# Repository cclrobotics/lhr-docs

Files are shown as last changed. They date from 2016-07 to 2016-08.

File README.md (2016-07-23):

# lhr-docs
Documentation for the Liquid Handling Robot

# Some resources for docmentation, git, and others.
- [Markdown Cheatsheet](https://github.com/adam-p/markdown-here/wiki/Markdown-Cheatsheet)
- [Atlassian Tutorials](https://www.atlassian.com/git/)

# Collaboration Documentation
- [Q & A with Pedro](https://github.com/cclrobotics/lhr-docs/blob/master/collaborations/Pedro-Terra/07-16-16_Q%26A.md)
- [Igor's Brain Github](https://github.com/arcturusbiocloud/igor-brain)
- [Igor Presentation](https://docs.google.com/presentation/d/1FlfPRDT8VCawL8XQLC20QvG_V_BuOnPto9CB1tIN5D0/edit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)

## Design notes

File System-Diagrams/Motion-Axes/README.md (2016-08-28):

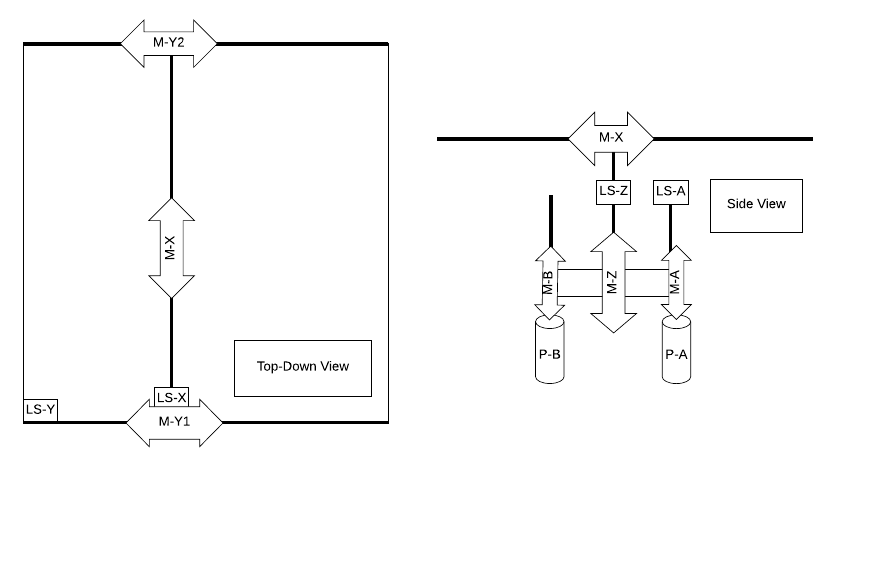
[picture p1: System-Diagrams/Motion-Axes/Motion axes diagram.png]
Motion Axes Diagram
 

|Key | Item | 
|---|---|
| M-X |X-Axis Motor |
| M-Y1 |Y-Axis Motor 1 |
| M-Y2 |Y-Axis Motor 2 |
| M-Z |Z-Axis Motor |
| P-A |Single Channel Pipette |
| P-B |Multi Channel Pipette |
| M-A |A-Axis Motor |
| M-B |B-Axis Motor |
| LS-X |X-Axis Limit Switch |
| LS-Y1 |Y-Axis Limit Switch | 
| LS-Z |Z-Axis Limit Switch |
| LS-A |A-Axis Limit Switch |

##Top-Down View
###X-Axis
There is one X-axis motor (M-X) which is attached to the pipettes and moves along the central beam. It uses the limit switch (LS-X) as it's minimum value, so that end is essentially zero for the X-axis. 
###Y-Axis
There are two Y-axis motors (M-Y1 and M-Y2) which are attached to either end of the central beam. Their phases are inverted so they will travel in synch together, moving the central beam. They use one limit switch (LS-Y1) as the minimum value for the Y-1 motor. This is the zero for the Y-axis. Only Y1 side hits it, and the stop signal should be sent to both Y motors. 

##Side View
###Z-Axis
There is one Z-axis motor (M-Z) which is attached to the set of pipettes and moves up and down perpendicular to the central beam. It uses the limit switch (LS-Z) as it's minimum value. This is the zero for the Z-axis. Moving along the Z-axis in a positive direction translates to moving **down**. 
###A-Axis
There is one A-axis motor (M-A) which is attached to the plunger of the single-channel pipette (P-A). It controls the depression of the plunger allowing us to propgram how much volume is pipetted up/down. It uses the limit switch (LS-A) as it's minimum value. This is the zero for the A-axis.
###B-Axis
There is one B-axis motor (M-B) which is attached to the plunger of the multi-channel pipette (P-B). It controls the depression of the plunger allowing us to propgram how much volume in pipetted up/down. There is currently no limit switch attached for this motor.

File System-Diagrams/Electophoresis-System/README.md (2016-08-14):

#Electophoresis System

http://www.instructables.com/id/Gel-electrophoresis-system-mini/

Diagram of the System here.

What are the components?
- Thing1
- DC-DC Converter
- AC-DC Converter
- More things...

Hardware and tools

From McMaster-Carr:

- 2-56 Hand Tap Taper, Cat # 2522A663
- Tap Wrench Sliding T-Handle, 0-1/4" (1.6-6.3mm) Tap Size, Cat # 2546A22
- 2x 2-56 Nylon Pan Head Slotted Machine Screw, 3/16" Length, Cat # 93135A076
- 4x 2-56 Nylon Pan Head Slotted Machine Screw, 1/8" Length, Cat # 93135A074
- Stainless steel wire, 0.01" diam. Cat # 9882K31
- 2x 6/32 Hex machine nuts Cat # 91841A007
- 2x Flat Washer, No. 6 Screw Size, 5/16"Cat #  92141A008

From TAP Plastics:

- IPS weld-on cement #3 or 4, Cat # 10792
- Hypo-type solvent cement applicator, Cat # 25658

From Digi-Key:

- 2x Banana plug, Cat #655K-ND
- Black banana plug cable, 36", Cat # 4771-36-0-ND
- Red banana plug cable, 36", Cat # 4771-36-2-ND
- 4x Rubber feet , Cat # SJ5012-0-ND

## Thing1

## DC-DC Converter 
It's based on the [Electrophoresis variable power supply](http://public.iorodeo.com/docs/electrophoresis_power_supply/)
by [IO Rodeo](http://iorodeo.com/).
It requires an input voltage from 10V (this hasn't been verified and should be) to 16V.
Manufacturer's recommended input voltage is 15V.
The original unit has a variable output from 25V to 100V. It has been modified to produce an output from 30V to 200V
by substituting the original 15K resistor R3, with a 7.5K resistor. A schematic of the circuit can be found
[here](http://public.iorodeo.com/docs/electrophoresis_power_supply/intro.html).

## AC-DC Converter
This is the thing you plug into the wall.
Triad Wall Mount AC Adapter  WSU150-1600
http://www.mouser.com/ProductDetail/Triad-Magnetics/WSU150-1600/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
It has a 15 V up to 1.6A output.
Note: Any replacement unit cannot have an output greater than 16V or damage to the [DC-DC Converter](#dc-dc-conv)

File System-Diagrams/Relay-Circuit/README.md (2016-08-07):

Several of the instruments are controlled using relay circuits so here is a little information about how they work.
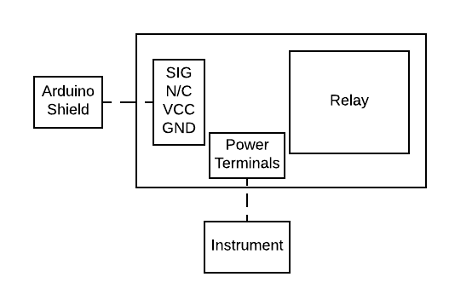
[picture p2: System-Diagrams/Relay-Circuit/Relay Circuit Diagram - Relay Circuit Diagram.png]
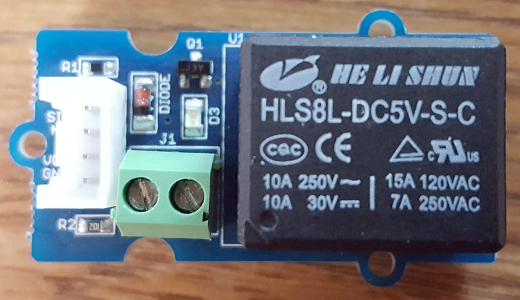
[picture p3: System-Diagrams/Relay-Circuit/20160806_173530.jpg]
 

- Four pin connector on the left links to a shield on the arduino board. The pins are as follows:
  - SIG: Signal from Arduino for the relay to open/close the circuit.
  - N/C: No connection (Doesn't actually do anything, only in place so a common connector can be used)
  - VCC: Provides power from the Arduino for the relay logic.
  - GND: Ground to the Arduino.

- Power Terminals switch power to one of the following instruments by completing their AC connection:
  - Shaker (on/off control)
  - Centrifuge (on/off control)
  - WL Transiluminator (on/off control)
  - UV Transiluminator (on/off control)
  - Incubator (Arduino uses a [hysteresis controller](https://www.google.com) to maintain temperature at 37&deg;C)
  - Igor Light (on/off control, suspected to be the overhead lights)
  - Gel Electrophoresis (on/off control)
  - Shaker Incubator Light (on/off control, there should be an incubator light to warm shaking tubes but I'm not sure where it is)
Some of these are assumed based on the [arduino code](https://github.com/griswaldbrooks/lhr-equipment-controller/blob/master/controller_firmware/controller_firmware.ino).

- Relay
  - Model #: HLS8L-DC5V-S-C
  - The relay receives a signal from the Arduino telling it to close or open the circuit. This will power on or off the instrument connected to the power terminals. Most of these can just be turned on/off (light boxes). In the case of the shaker and centrifuge, they are set to a specific rpm and just turned on/off by the Arduino. The hysteresis controller code is already loaded onto the Arduino. The Incubator also has a temperature sensor attached. When the temperature falls below 37&deg;C the Arduino turns the Incubator power source on (a lamp for now), once the temperature is above 3&deg;7C it is turned off. (We can make this more sophisticated in the future)

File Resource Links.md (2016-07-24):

# Components of the system

## Raspberry Pi
This is the main brain of the system. It is connected to every other aspect of the system and performs the high level planning involved.
There will be various types of code on it.   
- [Website](https://www.raspberrypi.org/)
- [Github](https://github.com/raspberrypi/)

## Smoothieboard 
Used to control stepper motors for XYZ translation and limit switches for setting up boundaries for each axis. 
It is programmed with g-code.   
- [Website](http://smoothieware.org/)
- [Github](https://github.com/Smoothieware/Smoothieboard) 

## Arduino Uno
Used to control the lab equipment (Centrifuge, shaker, etc. Note: PCR controlled via Rasberry pi).
You write sketches the arduino using the Arduino Software (IDE) which uses C/C++ by default.     
- [Website](https://www.arduino.cc/en/Main/ArduinoBoardUno)
- [Github](https://github.com/arduino/Arduino)

## Pronterface
They run a software suite called PrintRun which allows you to communicate with 3D printers, but we will be using it to communicate with the CNC.
This suite is on the rasberry pi and sends g-code to smoothie board.    
- [Website](http://www.pronterface.com/)
- [Github](https://github.com/kliment/Printrun)

# Previous Work

## Pedro Terra  
- [Website](http://www.pedroterralab.com/)

## OpenTrons
The original liquid handling robot, made by Arcturus, that Pedro and Luis modified and expanded into "Igor."  
- [Website](https://opentrons.com/)
- [Github](https://github.com/OpenTrons/otone_docs/blob/master/README.md)
- [Open source bioserver](https://forum.arcturus.io/t/open-source-bioserver/17/9)    
This is a great place to see the progress Pedro and Luis made.
- [BioBot 1.0 Assembly Guide](https://synbiota.com/projects/1p_XD0znG/entries/0DATTrmqW?preview=true)  
Note: The assembly guide is for the original OpenTrons DIY BioBot. Pedro and Luis' "Igor" is larger, includes more components, and most importantly is using the Smoothieboard NOT the TinyG. Therefore it's best we dont' follow this to a T.

### Google Drives
- [OpenTrons](https://drive.google.com/folderview?id=0B5OBQhwEUbwUNXZKVWYxeHo2elE&usp=drive_web)
- [bioserver](https://drive.google.com/folderview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)
- [igor general photos](https://drive.google.com/folderview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)
- [igor bioserver parts](https://drive.google.com/folderview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)

It won't be necessary to exaustivly read through all of their documentation, but these should be good sources to look at if we run into any trouble figuring the system out. I will be compiling files and information from these sources throughout the repo in appropriate locations (ex. photos in a photos folder).

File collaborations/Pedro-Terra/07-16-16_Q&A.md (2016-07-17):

We set up a skype call with Pedro to find out a lot of information that would help us in making the LHR work. It was a very enlightening conversation and I would like to update you all with the information we discussed. I will update any files and information Pedro sends us promply. 
(Thank you Pedro for all of your help thus far!!)

# Summarised Q&A with Pedro:

1. Where is there documentation for all of the aspects of this system (code, system diagrams, circuit diagrams, images, files, etc.)?

  May have sketches in notebooks.
  Models of system available in sketch up files. 

  [Smoothie board website](http://smoothieware.org/) has useful information regarding the CNC wiring, XYZ motor and limit switch code. 
  Smoothie board handles all CNC movement. A axis for plunger to choose volume to pipette is controlled through the smoothie board. All ejection, dispensing, and aspiration is accomplished with one motor. All motor uncertainty is 0.1 mm. 
  [Pronterface](http://www.pronterface.com/) used for doing cnc commands with macros and custom functions. 
  Did not use [Mix.bio](Mix.bio) to write protocols, that was only the [OpenTrons](https://opentrons.com/) people (Will and Chu).
  All code was custom, mostly g-code. Code was written to control the CNC, PCR, incubator lamp, and web functionality. Communicate with Luis Silva for more information about the web connectivity, remote operation and general code questions.

2. How much of the system worked? 
  * **CNC**: 
  
    CNC worked, grabbing and releasing pipette accessories (petri dish,  gel electrophoresis tray) worked, pipetting liquids worked. Main problem how to attach pipette to arm. Pipette attachment to accessories would be affected by the plastic portion of the pipette bending. Pipette not supported well by attachment to robot arm. 
  * **Laser/Camera System**: 
  
    Was used to align pipette during remote operation. Not directly implemented in the control loop for XYZ translation. 
  * **Fridge**: 
  
    Fridge circuit should connect to arduino. 
Fridge is meant to operate between -20˚C (temperature the fridge is intended to be used at) at the bottom and -5˚C near the top. 
Expected to have a jack inside of the fridge to move things closer to the top so they can thaw. 
Should have car jacks. 
  * **Incubator**:
  
    Function was used to turn the incubator on and off to maintain a set temperature. (Temperature sensor that we thought was used for the fridge is actually used to sense this temperature.)
  * **Light Boxes**: 
  
    Not fully implemented. Should use one camera for each lightbox to imagine petri dishes and gels. 
  * **PCR**: 
  
    PCR was connected to Raspberry pi to upload protocols. Check [OpenPCR](http://openpcr.org/) for documentation.
  * **Centrifuge**: 
  
    Not fully implemented. 
  * **Shaker**: 
    
    Not fully implemented. 
  * **Gel Electrophoresis**: 
    
    Not fully implemented. 
  * **Eppendorf tube capper**: 
  
    Separate system used to open and re-cap eppendorf tubes. Not fully implemented or integrated with LHR. 

3. How did the camera system work?

  Used two cameras for alignment with the lasers and gcode for x-y location. 
  Two or three cameras for streaming and remote operation, these were attached to the axes. 
  Two cameras for transiluminator.
  Cameras all plug into raspberry pi. 

4. How did you move eppendorf/PCR tubes ?

  Did not move eppendorf tubes, only PCR tubes. PCR tubes cut into two tube sections. One tube was used to attach the pipette in order to move both tubes around, the second tube was actually used to do labwork in. 
  
5. Were you any exernal resource to find protocols to run the robot with?

  Although OpenTrons used [Mix.bio](Mix.bio) protocols ours were all custom and written in g-code using pronterface. 

6. What are the other rasbperry pis, second PCR, and extra usb hub for?

  These are all redundancies in case any parts of the system need to be replaced. The system should only use one raspberry pi, one PCR, one USB hub, and one arduino. 

7. How do you connect the system to the internet?

  All internet capability should be through the raspberry pi (this suggests the pi should have a rasberry server on it). Contact Luis to for further questions about the internet connectivity.

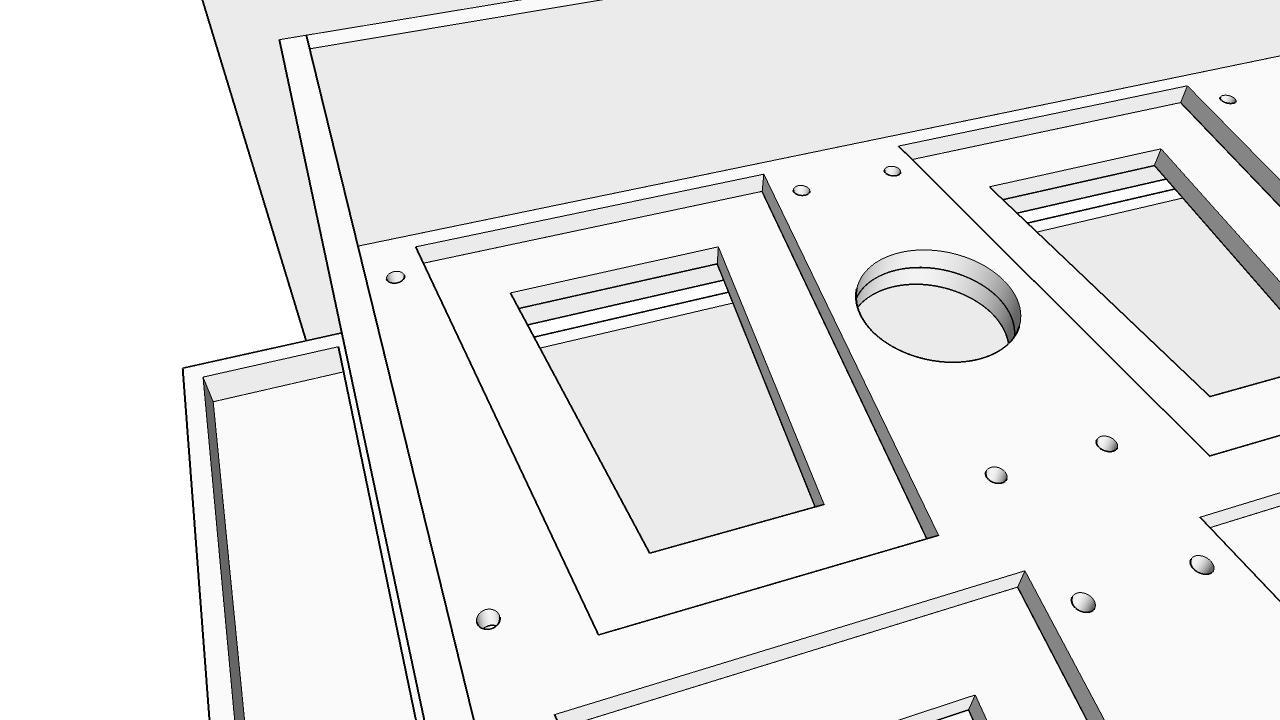
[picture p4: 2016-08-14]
Image/Design-Images-CAD/Arcturus BioCloud incub and robotic System0006.jpg

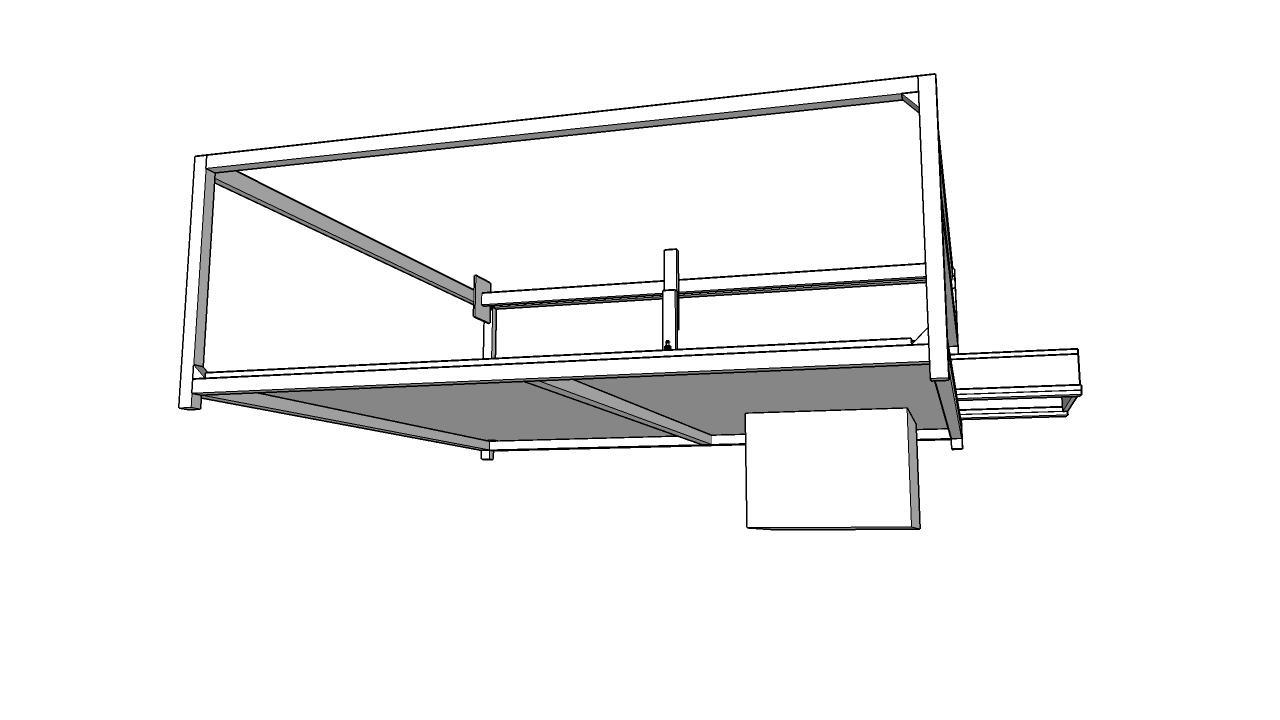
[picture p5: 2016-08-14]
Image/Design-Images-CAD/Arcturus BioCloud incub and robotic System0013.jpg

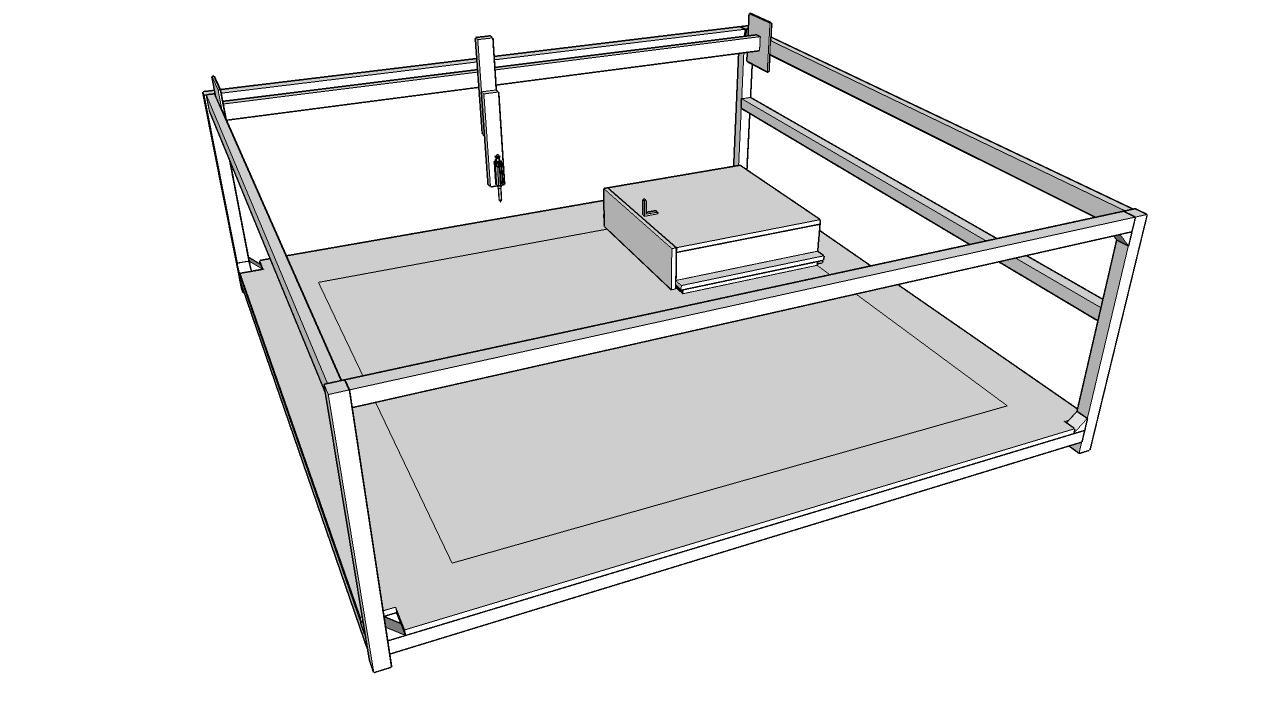
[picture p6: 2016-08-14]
Image/Design-Images-CAD/Arcturus BioCloud incub and robotic System0001.jpg

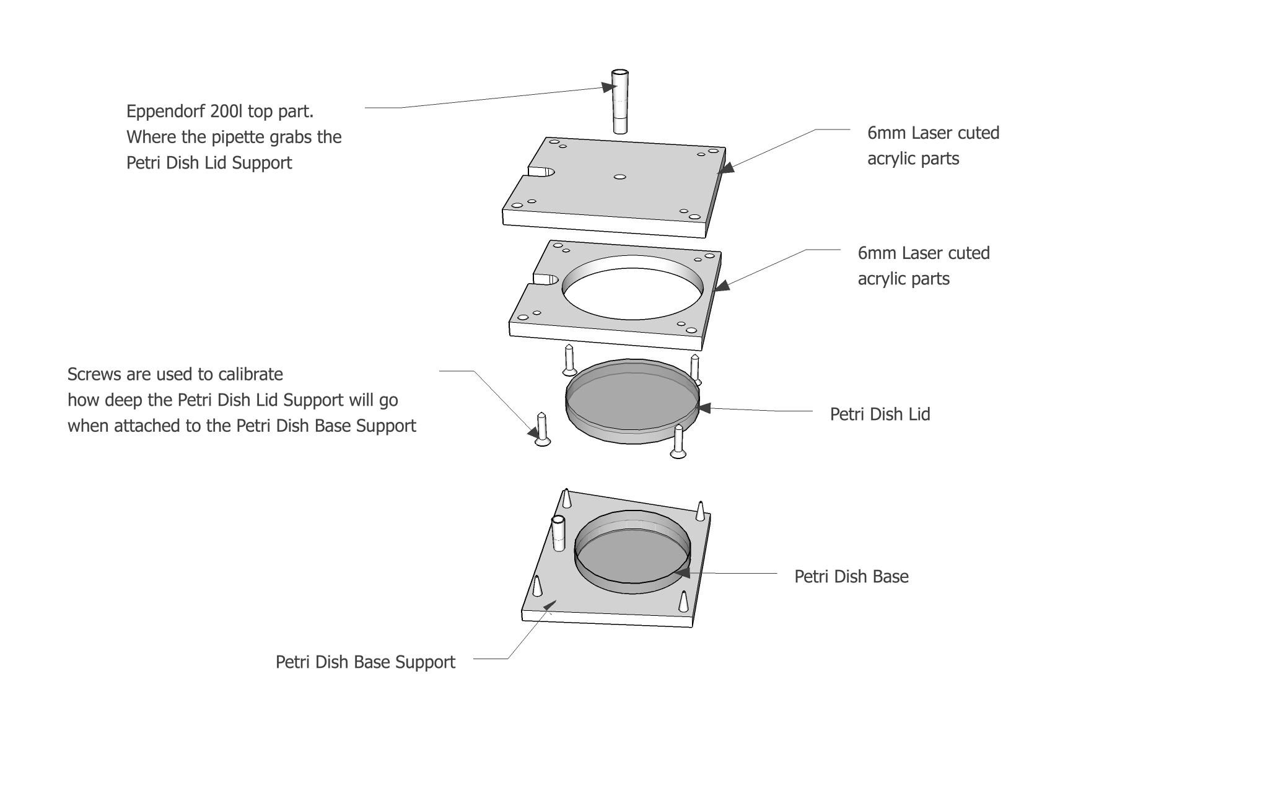
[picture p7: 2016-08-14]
Image/Design-Images-CAD/Dish system.jpg

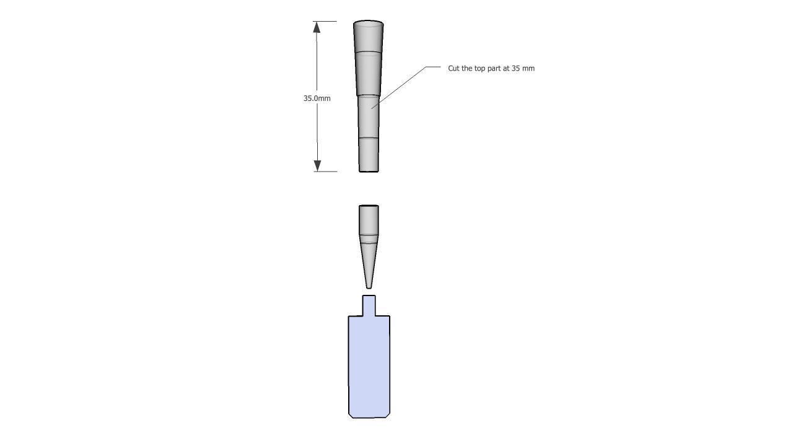
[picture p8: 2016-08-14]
Image/Design-Images-CAD/plating tips BioServer Arcturus BioCloud0003.jpg

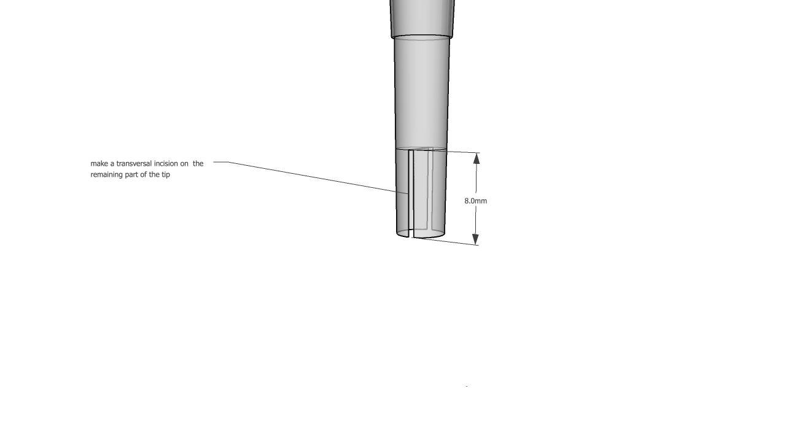
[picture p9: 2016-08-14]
Image/Design-Images-CAD/plating tips BioServer Arcturus BioCloud0004.jpg

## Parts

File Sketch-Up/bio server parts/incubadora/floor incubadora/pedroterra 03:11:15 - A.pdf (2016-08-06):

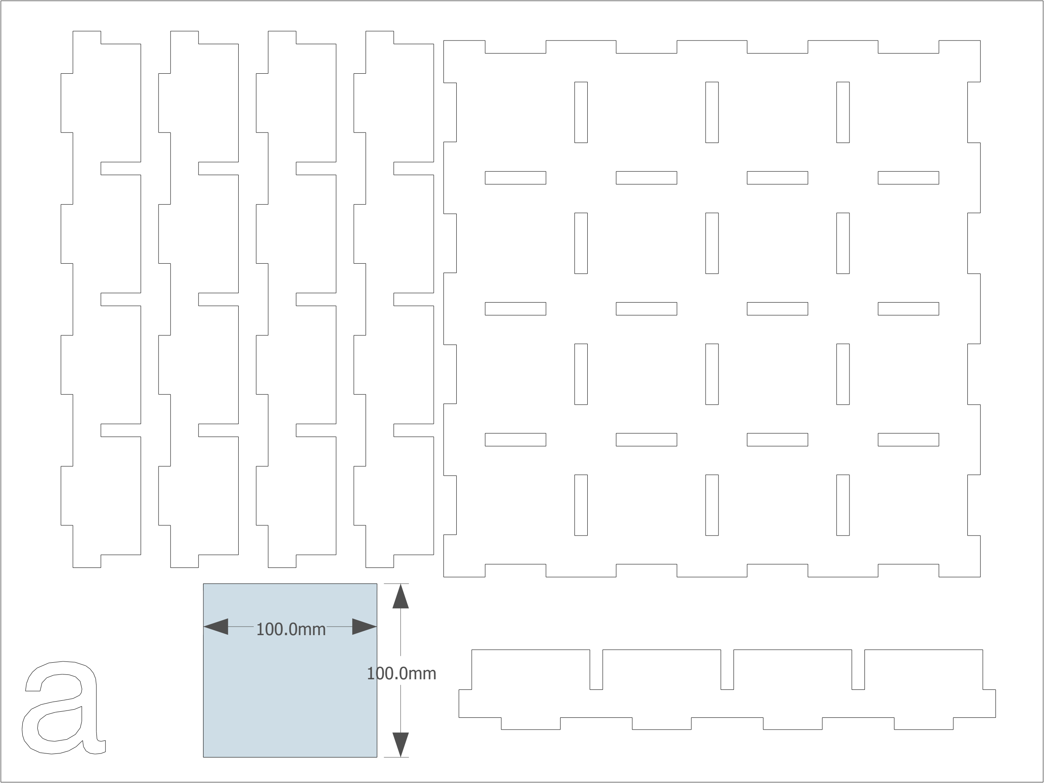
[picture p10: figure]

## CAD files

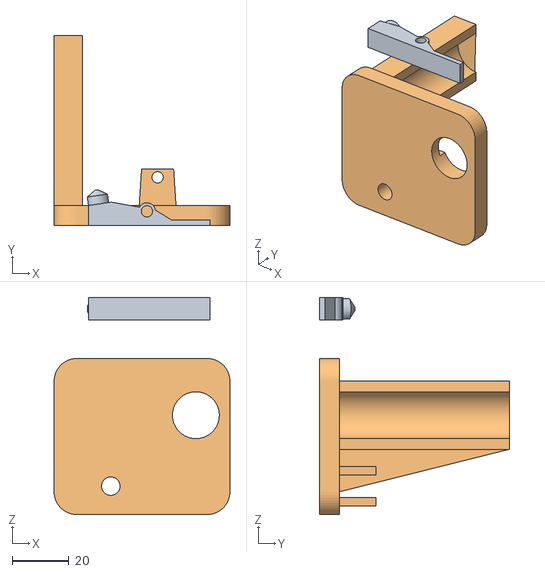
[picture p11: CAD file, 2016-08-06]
Sketch-Up/bio server parts/air vavula/air valvula.obj
62.0 x 67.0 x 76.5
Mesh1 Component_5_1 Model
Mesh2 Model

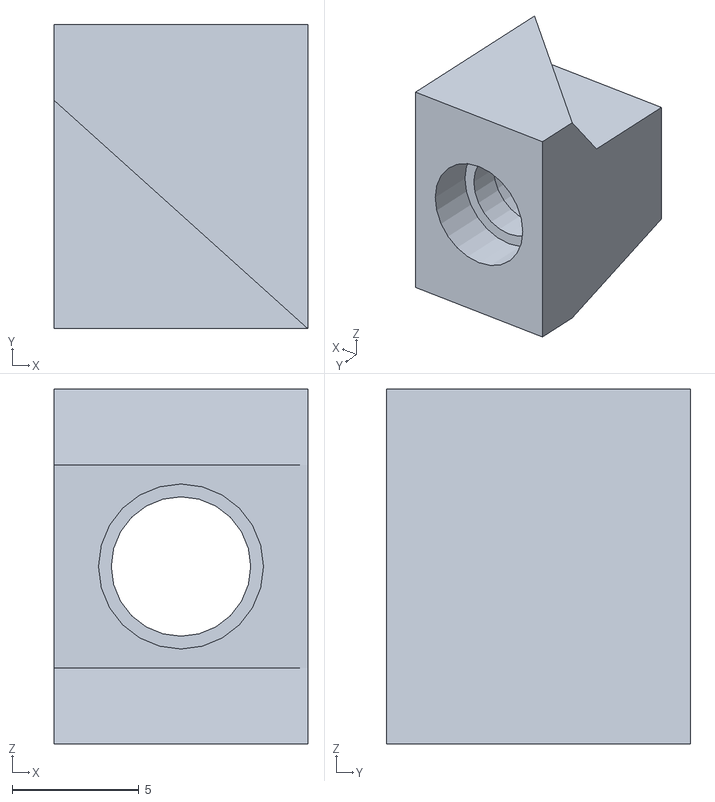
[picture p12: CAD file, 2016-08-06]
Sketch-Up/bio server parts/autonoumus tip loader/peso para tip.obj
10.0 x 12.0 x 14.0

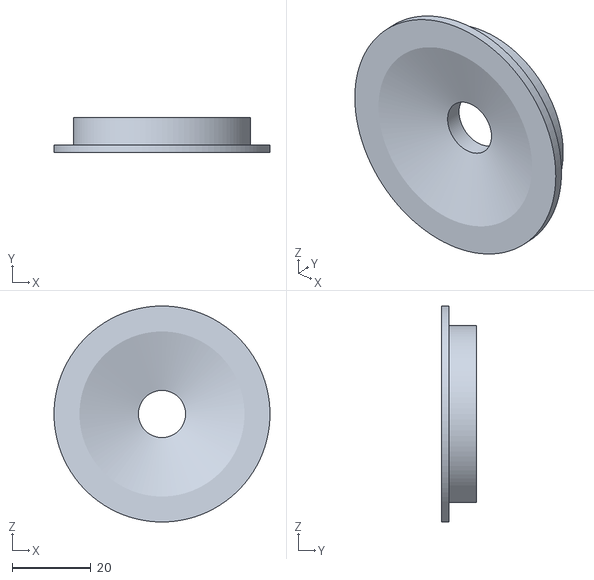
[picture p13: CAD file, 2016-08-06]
Sketch-Up/bio server parts/bacteria ice container/bacteria ice cap.obj
55.0 x 9.00 x 55.0

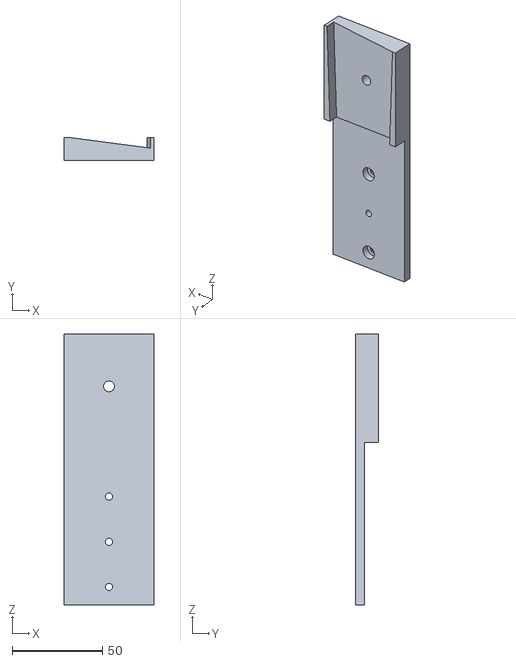
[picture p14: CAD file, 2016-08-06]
Sketch-Up/bio server parts/camera arm support/suporte camera.obj
50.0 x 13.0 x 150.0

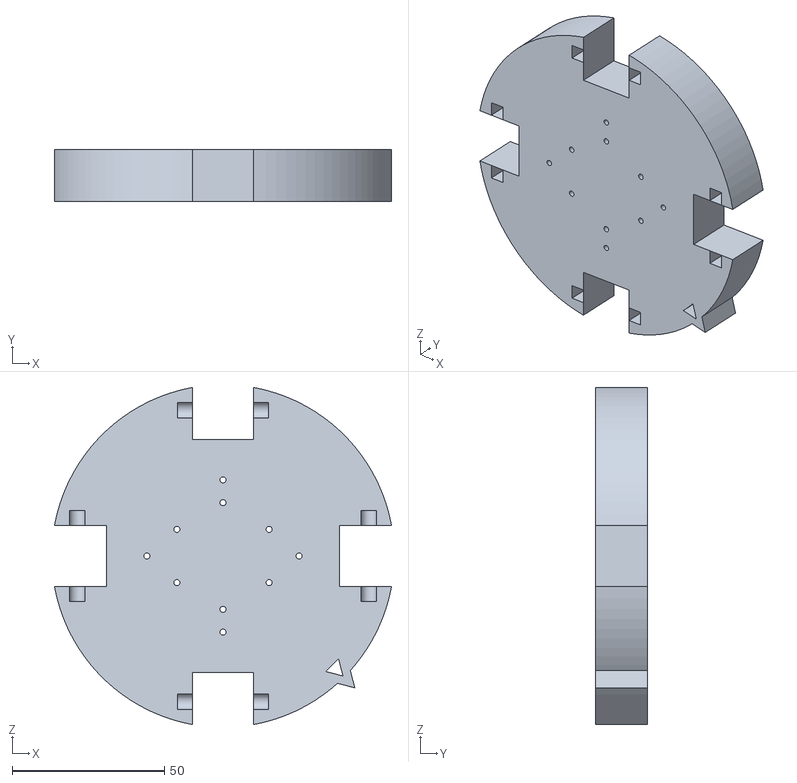
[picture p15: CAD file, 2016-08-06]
Sketch-Up/bio server parts/centrifuge/centrifuge 2.obj
110.7 x 17.0 x 110.7

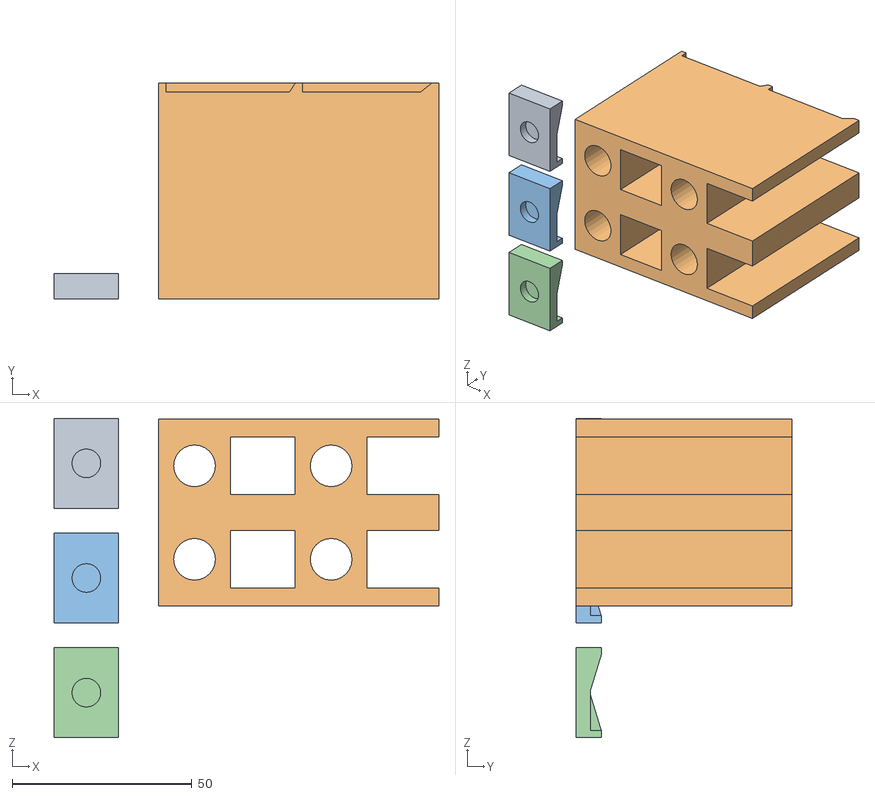
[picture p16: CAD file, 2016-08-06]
Sketch-Up/bio server parts/dna holder suport/quatro dna suport.obj
107.1 x 60.0 x 88.8
Mesh1 Component_3_1 Model
Mesh2 Component_4_1 Model
Mesh3 Component_3_2 Model
Mesh4 Component_3_3 Model

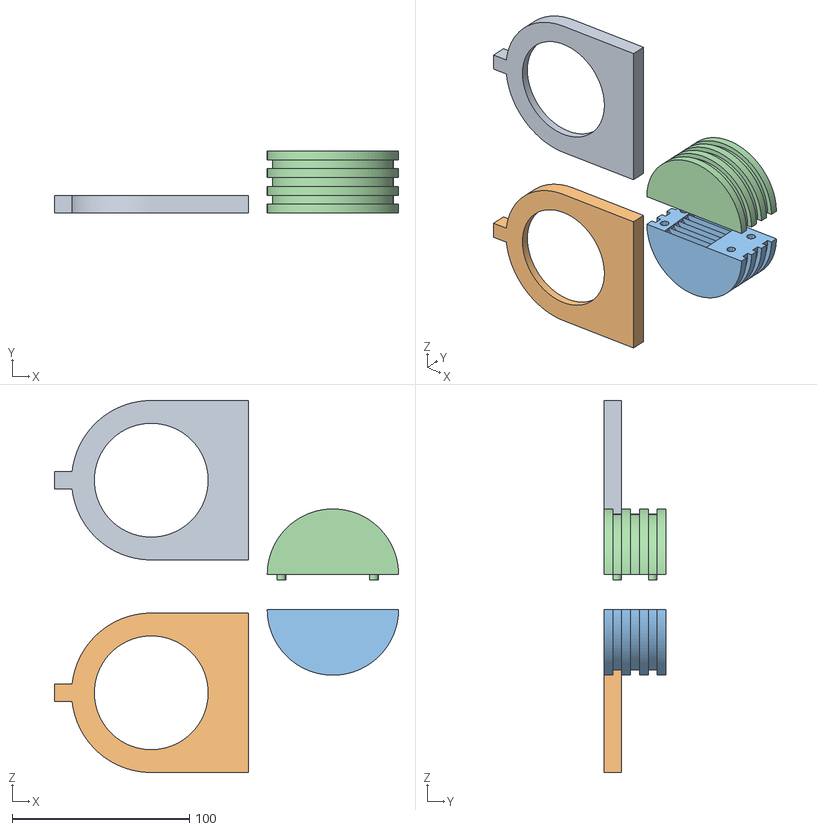
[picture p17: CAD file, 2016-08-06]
Sketch-Up/bio server parts/estudo pipeta giratoria/estudo segurar pipeta for print.obj
194.3 x 35.0 x 210.0
Mesh1 Group1 Model
Mesh2 Group2 Model
Mesh3 Component_2_1 Model
Mesh4 Component_1_1 Model

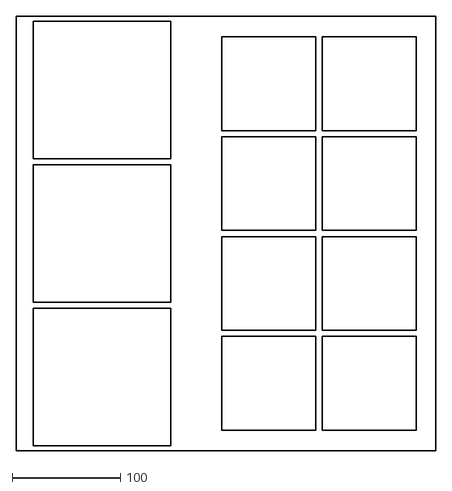
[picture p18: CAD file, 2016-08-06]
Sketch-Up/bio server parts/grid petridish/grid petri g e p .dxf
386.9 x 400.5

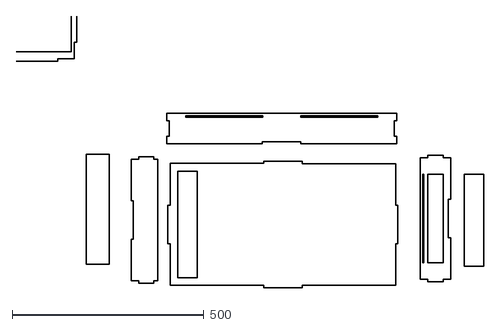
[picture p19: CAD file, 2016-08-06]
Sketch-Up/bio server parts/incubadora/a/a1.dxf
1218.1 x 707.5

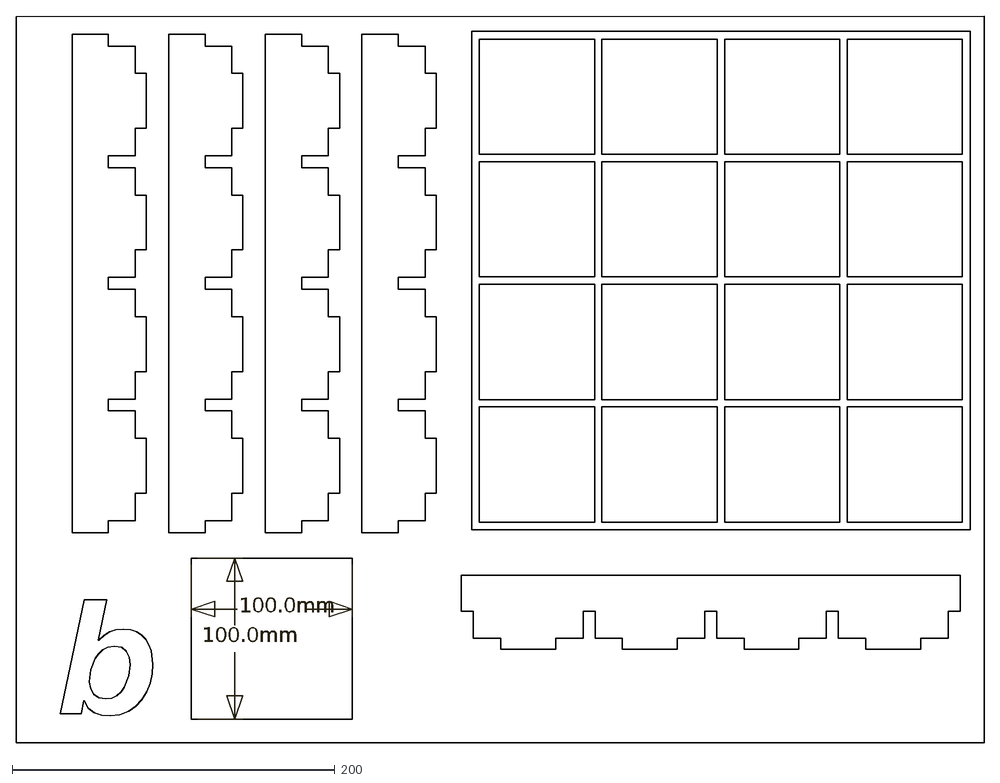
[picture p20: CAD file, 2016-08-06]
Sketch-Up/bio server parts/incubadora/floor incubadora/pedroterra 03:11:15 - B.dxf
100.0mm

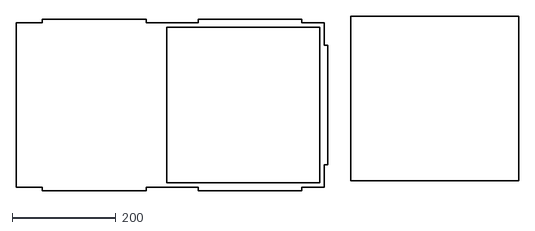
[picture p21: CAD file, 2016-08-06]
Sketch-Up/bio server parts/incubadora/incub a.dxf
967.8 x 335.8

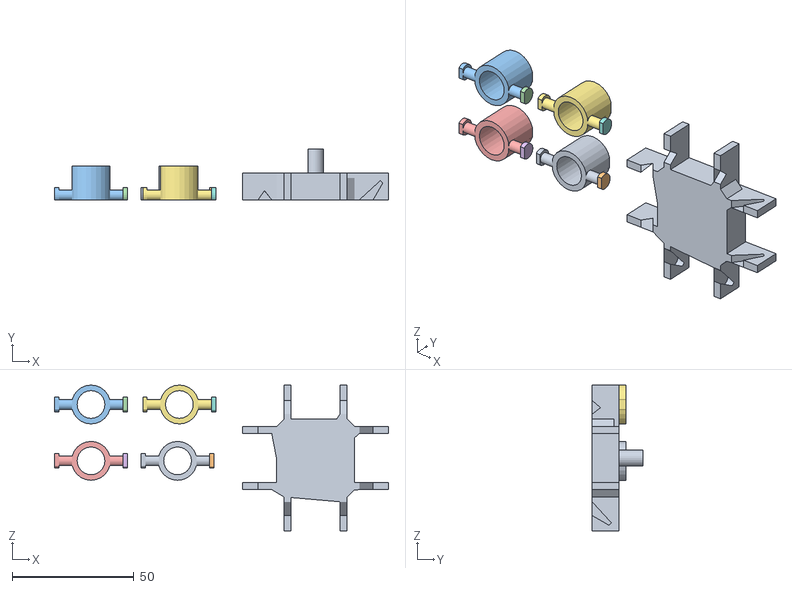
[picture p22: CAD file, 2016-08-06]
Sketch-Up/bio server parts/centrifuge/centrifuge.obj
137.3 x 21.1 x 60.0
Mesh1 Component_2_1 Model
Mesh2 Component_2_1 Model
Mesh3 Component_2_2 Model
Mesh4 Component_2_2 Model
Mesh5 Component_2_3 Model
Mesh6 Component_2_3 Model
Mesh7 Component_2_4 Model
Mesh8 Component_2_4 Model
Mesh9 Component_4_1 Model

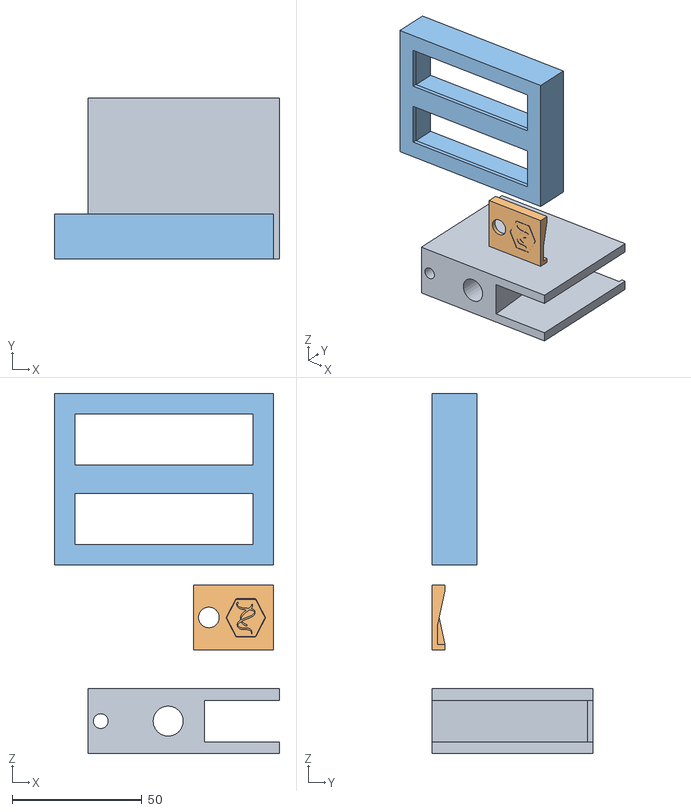
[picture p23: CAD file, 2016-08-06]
Sketch-Up/bio server parts/dna holder suport/dna suport holder.obj
86.9 x 62.0 x 138.9
Mesh1 Component_2_1 Model
Mesh2 Component_3_1 Model
Mesh3 Component_1_1 Model

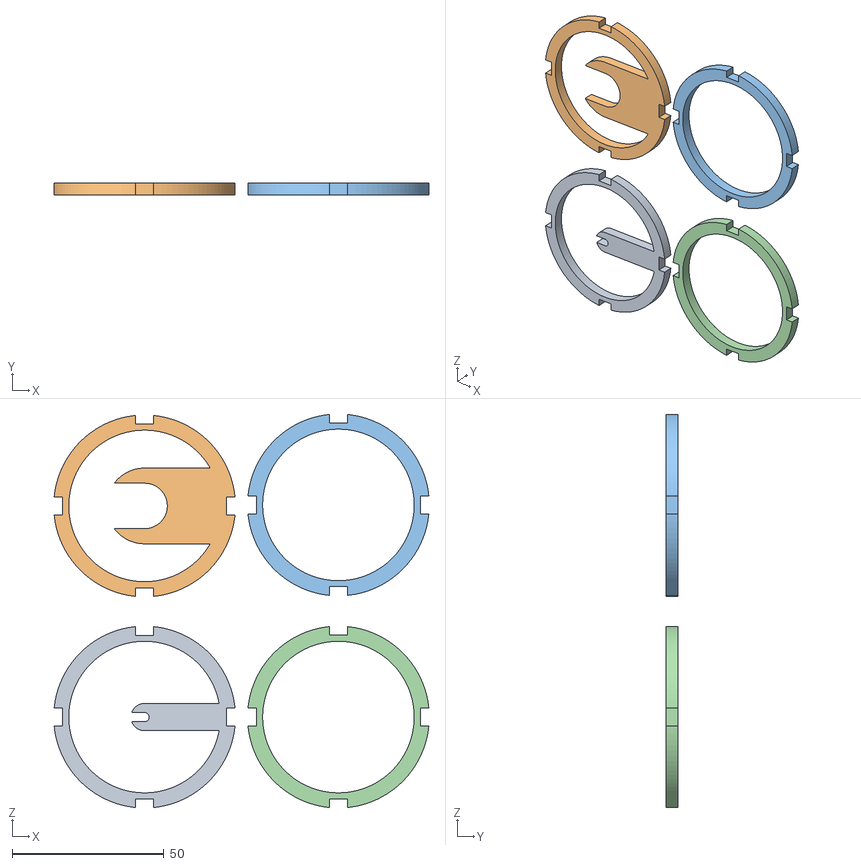
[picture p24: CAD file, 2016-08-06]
Sketch-Up/bio server parts/estudo pipeta giratoria/estudo segurar pipeta.obj
123.6 x 4.00 x 129.7
Mesh1 Component_1_1 Model
Mesh2 Component_2_1 Model
Mesh3 Component_3_1 Model
Mesh4 Component_3_2 Model

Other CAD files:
Sketch-Up/bio server parts/incubadora/a/a2.dxf
Sketch-Up/bio server parts/incubadora/floor incubadora/pedroterra 03:11:15 - A.dxf
Sketch-Up/bio server parts/centrifuge/centrifuge container holder.obj
Sketch-Up/bio server parts/dna holder suport/dna container lid 2.obj
Sketch-Up/bio server opentrons.skp
Sketch-Up/bio server opentrons~.skp
Sketch-Up/bio server parts/air vavula/AIR VALVULA TESTE.skp
Sketch-Up/bio server parts/air vavula/air valvula.skp
Sketch-Up/bio server parts/air vavula/air valvula~.skp
Sketch-Up/bio server parts/air vavula/air valvula~~.skp
Sketch-Up/bio server parts/assembly holder/assembly FP.skp
Sketch-Up/bio server parts/assembly holder/assembly holder.skp
Sketch-Up/bio server parts/assembly holder/assembly holder~.skp
Sketch-Up/bio server parts/autonoumus tip loader/peso para tip.skp
Sketch-Up/bio server parts/bacteria ice container/bacteria ice cap.skp
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

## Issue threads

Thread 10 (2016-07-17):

Check limit switches

griswaldbrooks, 2016-07-17:
Verify that all of the limit switches work.
Some of the soldering is suspect.

griswaldbrooks, 2016-07-17:
This issue was moved to cclrobotics/lhr-testing#1

griswaldbrooks, 2016-07-17:
This issue was moved to cclrobotics/lhr-testing#2

Closed 2016-07-17.

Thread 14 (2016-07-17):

Add system diagrams to docs

griswaldbrooks, 2016-07-17:
Add the current version of the system diagrams and other info. Also, the mechanical dimensions for the new cabinet need to be added to the mechanical repo.
@ tamarum

griswaldbrooks, 2016-08-03:
https://github.com/cclrobotics/lhr-testing/issues/12#issuecomment-237361186 has the model number for the electrophoresis.

griswaldbrooks, 2016-08-03:
Maybe start putting things on the wiki?

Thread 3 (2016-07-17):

Power on check the system components.

griswaldbrooks, 2016-07-17:
Need to verify that the system components work.

Power on checks:
- [ ] Raspberry Pi
- [ ] Arduino
- [ ] Smoothieboard
- [ ] Electrophoresis voltage regulator
- [ ] OpenPCR
- [ ] Centrifuge
- [ ] Shaker
- [ ] Freezer
- [ ] Freezer arduino
- [ ] UV Lightbox
- [ ] VL Lightbox
- [ ] Incubator

griswaldbrooks, 2016-07-17:
This issue was moved to cclrobotics/lhr-testing#9

Closed 2016-07-17.

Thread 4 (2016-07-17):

Check for Pronterface on Raspberry Pi

griswaldbrooks, 2016-07-17:
Get into the Raspberry Pi and see where the Pronterface code/program is.

griswaldbrooks, 2016-07-17:
This issue was moved to cclrobotics/lhr-testing#8

Closed 2016-07-17.

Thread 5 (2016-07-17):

Test the relays

griswaldbrooks, 2016-07-17:
Load a basic sketch onto the Arduino and switch the relays.

griswaldbrooks, 2016-07-17:
This issue was moved to cclrobotics/lhr-testing#7

Closed 2016-07-17.

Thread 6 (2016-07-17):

Test the Electrophoresis Voltage controller

griswaldbrooks, 2016-07-17:
Hook up the Electrophoresis controller and see if the knob modulates the voltage.

griswaldbrooks, 2016-07-17:
This issue was moved to cclrobotics/lhr-testing#6

Closed 2016-07-17.

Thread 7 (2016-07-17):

Test the Smoothieboard

griswaldbrooks, 2016-07-17:
Do a basic hookup of the Smoothieboard with some stepper motors and send some commands.
Most likely use Pronterface to run the motors.

griswaldbrooks, 2016-07-17:
This issue was moved to cclrobotics/lhr-testing#5

Closed 2016-07-17.

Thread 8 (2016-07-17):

Read the temperature sensors

griswaldbrooks, 2016-07-17:
Load a basic sketch onto the Arduino to read the temperature/humidity sensor.

griswaldbrooks, 2016-07-17:
This issue was moved to cclrobotics/lhr-testing#4

Closed 2016-07-17.

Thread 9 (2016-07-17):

Make Arduino test script

griswaldbrooks, 2016-07-17:
Create a test script that can be loaded onto the Arduino to actuate the relays and print out the temperature data and relay state.

Should be able to connect to the Arduino through TeraTerm and send relay command and printout system state.

griswaldbrooks, 2016-07-17:
This issue was moved to cclrobotics/lhr-testing#3

Closed 2016-07-17.

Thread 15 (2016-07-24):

Diagram how the relays work

tamarum, 2016-07-24:
Create a clear diagram of how the relays are being used in this system including all connector pins (power in, ground, signal, N/C) and where the component is connected.

tamarum, 2016-08-07:
Made a [diagram](https://github.com/cclrobotics/lhr-docs/blob/master/System-Diagrams/Relay-Circuit/Relay%20Circuit%20Diagram%20-%20Relay%20Circuit%20Diagram.png) and [explanation](https://github.com/cclrobotics/lhr-docs/blob/master/System-Diagrams/Relay-Circuit/README.md) for the relays. I will discuss how they are connected to the Arduino in a separate file.

Closed 2016-08-07.

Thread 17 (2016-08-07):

Diagram & document smoothieboard connections and version information

tamarum, 2016-08-07:
Including:
- Power source
- Motors
- Limit switches
- Raspberry pi communication
- Possible temperature reading/writing

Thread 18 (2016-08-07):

Tutorial: How to read and update the smoothieboard config file

tamarum, 2016-08-07:
Explain what parameters need to be set and which variables represent which motors.

ddigor, 2016-08-11:
[LHR_Smoothie.xlsx](https://github.com/cclrobotics/lhr-docs/files/412507/LHR_Smoothie.xlsx)
Collated some motor stuff into tiny spreadsheet.

Endstops seem to have dedicated pins
  alpha - config file lines 197, 198
  beta - config file lines 202, 203
  gamma - config file lines 207, 208
and dedicated enabling as limits
  config file lines 218, 219, 220
Unclear how to deal with switches on the two motor Y axis
  wire OR will work for an emergency stop, but not good for re-homing after a tooth slip
Unclear how to do use limit inputs for more than 3 axes,
  like for the pipette plunger A and B axes

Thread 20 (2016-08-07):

Document motor parameters

tamarum, 2016-08-07:
This includes model number, current rating, axis on cartesian machine, label on smoothie board, limit switch port, naming in config file.

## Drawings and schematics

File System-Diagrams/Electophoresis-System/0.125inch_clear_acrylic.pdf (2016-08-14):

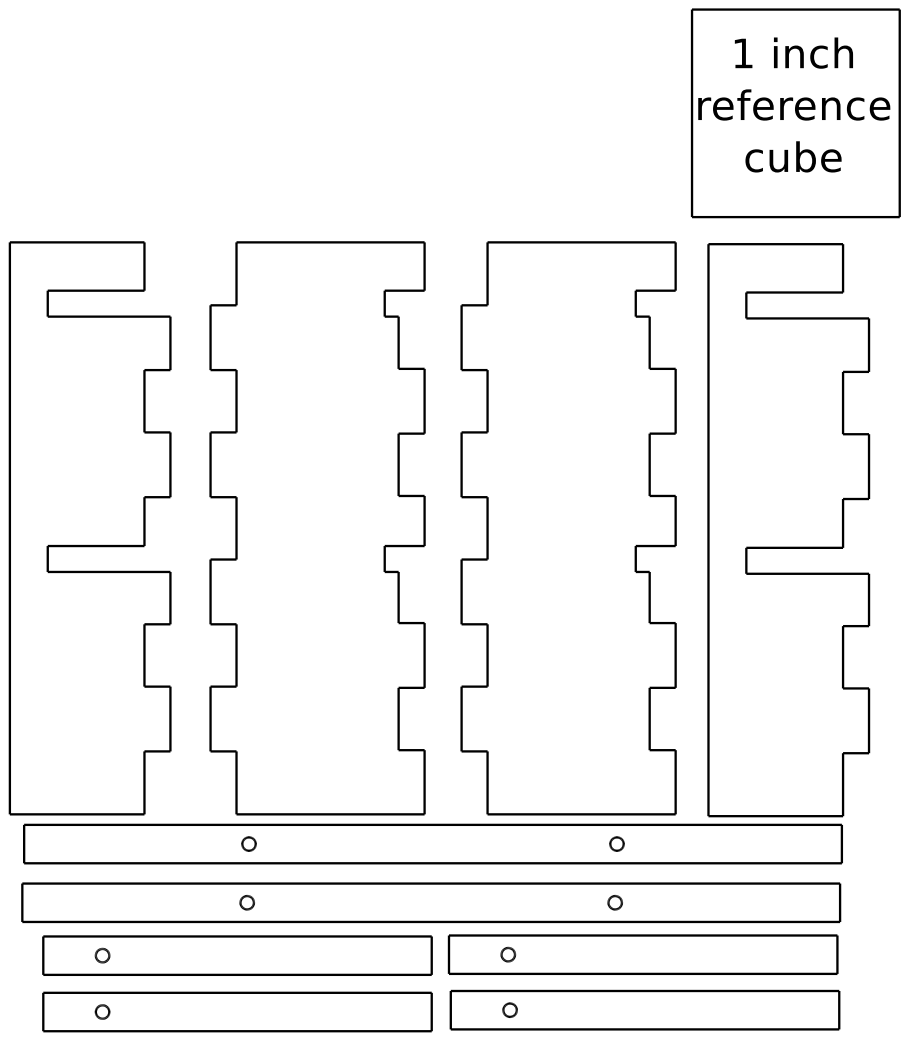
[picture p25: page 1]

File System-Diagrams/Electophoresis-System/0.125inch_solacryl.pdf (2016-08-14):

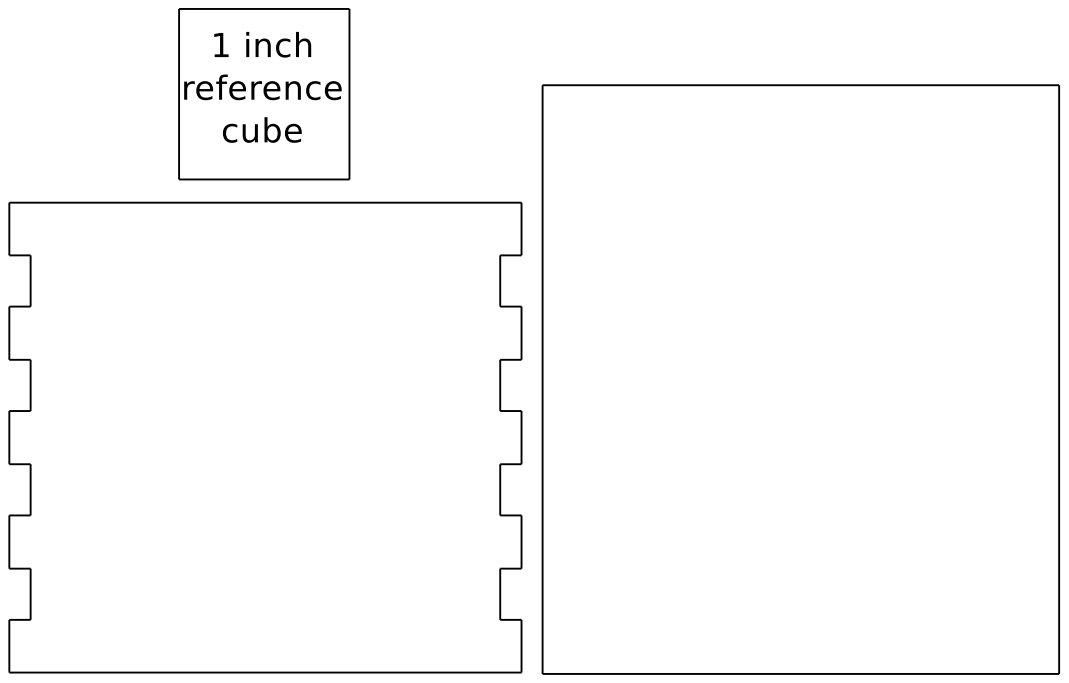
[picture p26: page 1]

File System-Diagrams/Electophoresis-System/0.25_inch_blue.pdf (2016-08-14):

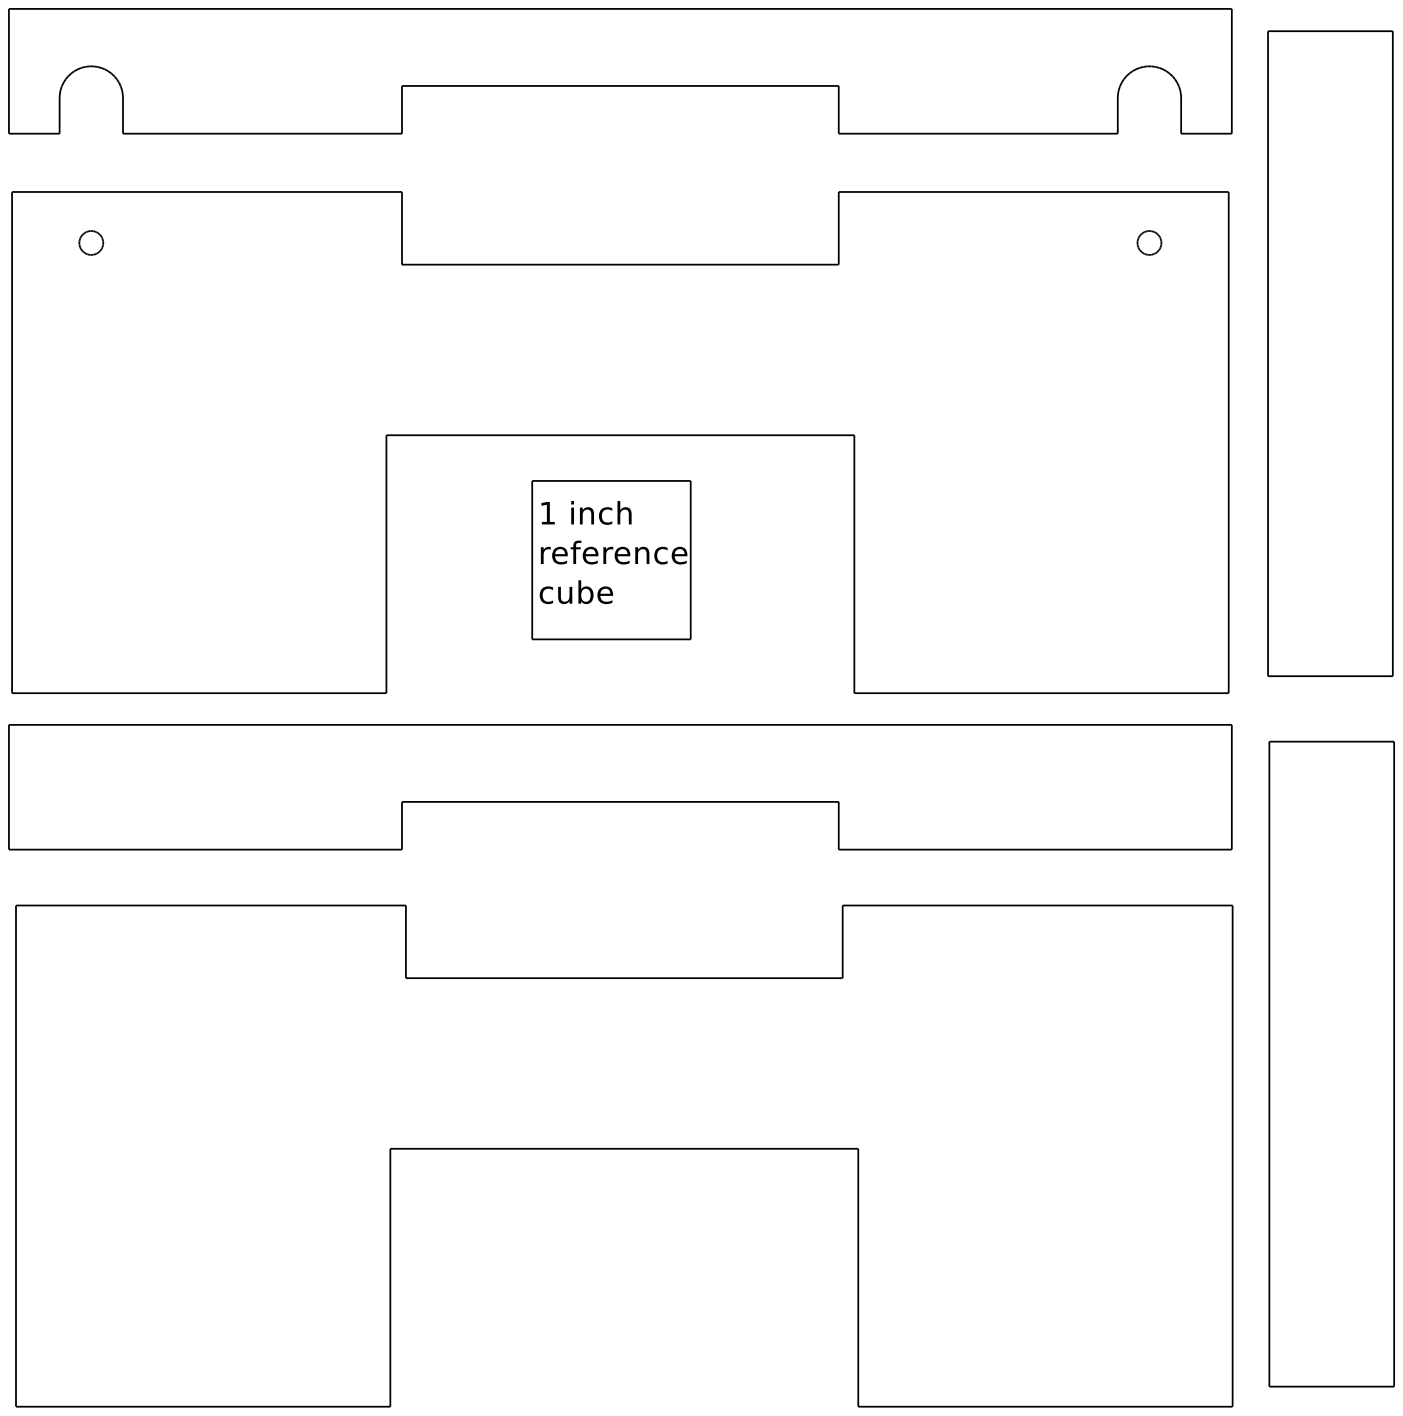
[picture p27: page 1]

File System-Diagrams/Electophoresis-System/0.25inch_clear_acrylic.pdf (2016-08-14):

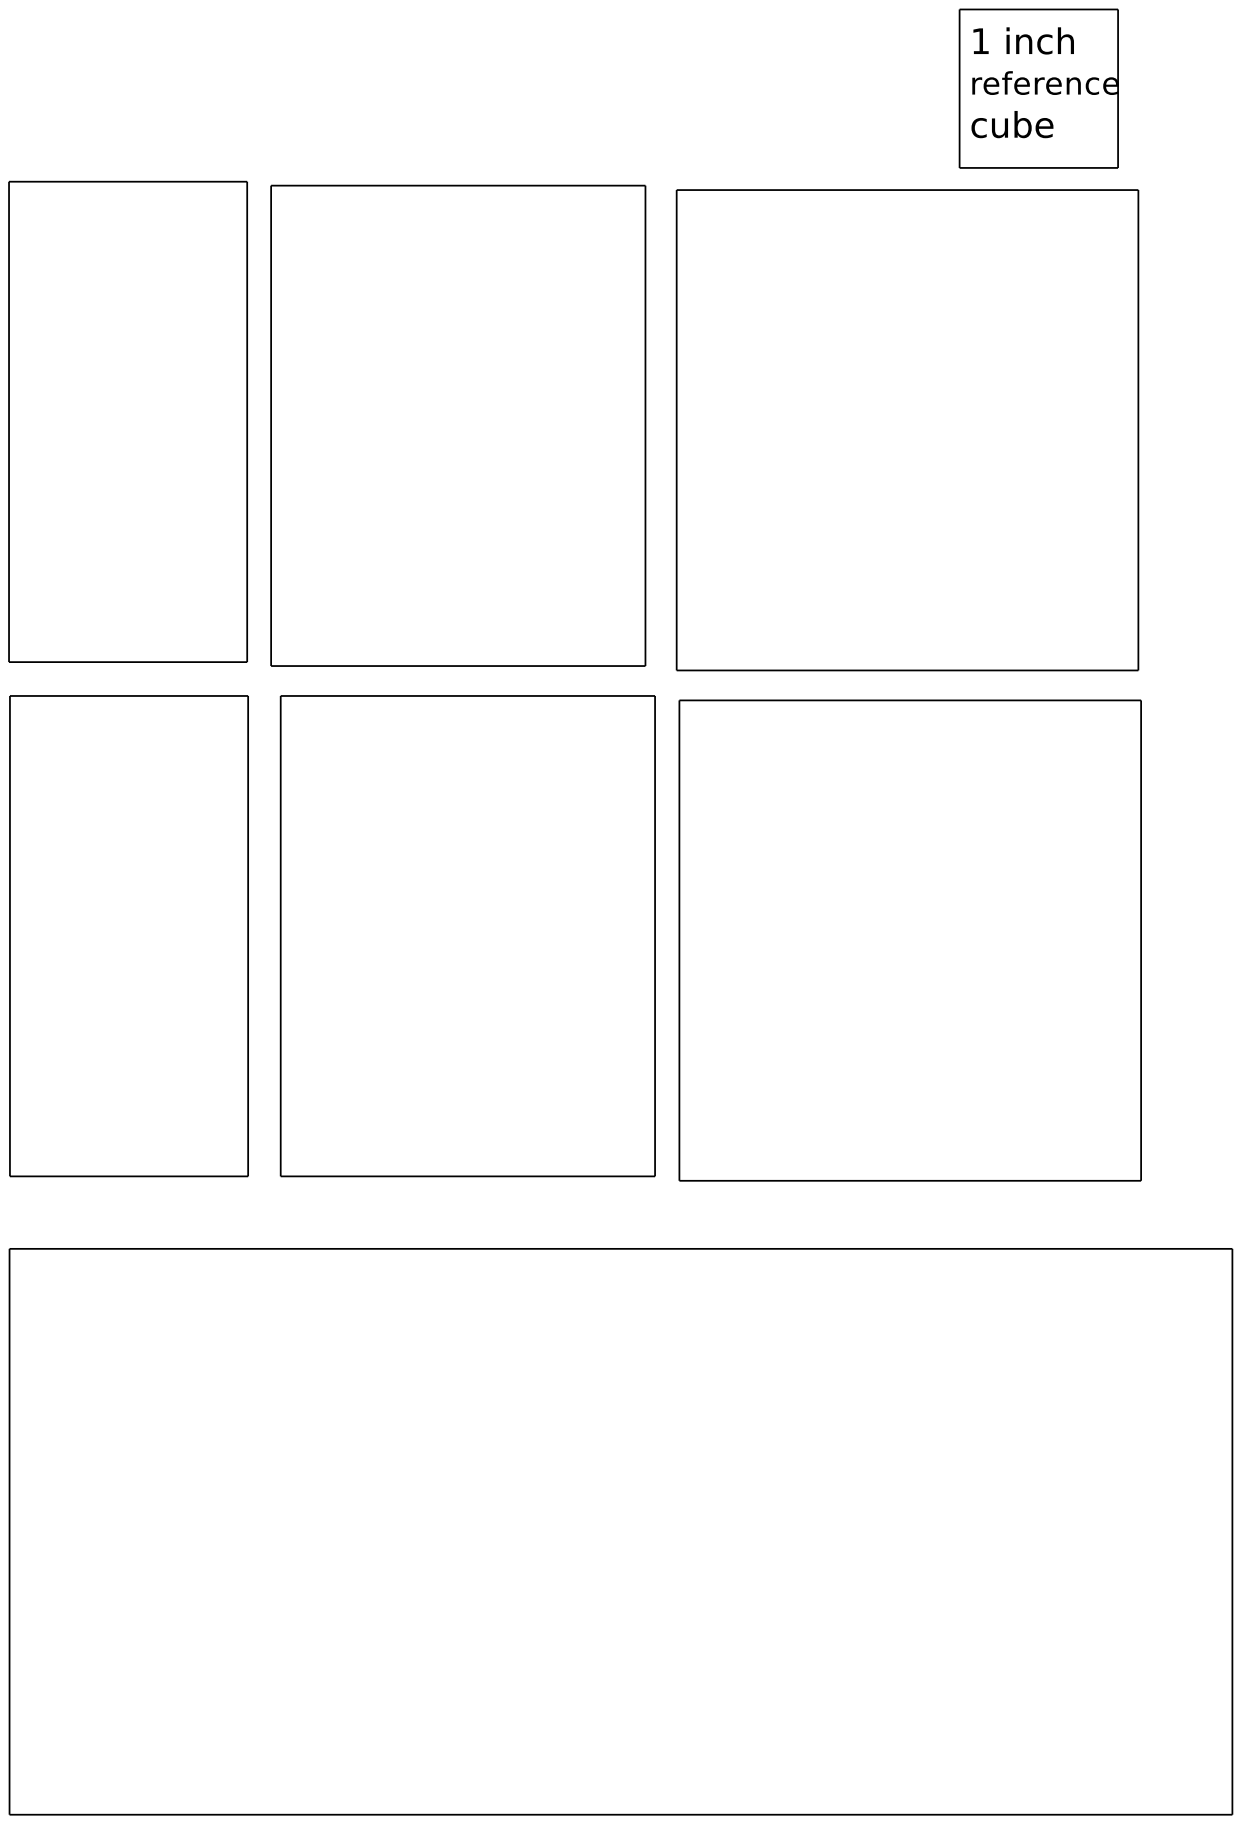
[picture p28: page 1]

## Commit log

2016-07-16 Fixed the parens vs square brackets.
2016-08-07 Updated overview of the relays.
    Will add more information about which relays go to which unit once we diagram the Arduino shield.
2016-08-14 Create Design Images CAD
2016-08-14 Create Readme.md
    Design images done in CAD
2016-08-14 Add files via upload
    Design Images done in CAD I found at https://forum.arcturus.io/t/open-source-bioserver/17/12

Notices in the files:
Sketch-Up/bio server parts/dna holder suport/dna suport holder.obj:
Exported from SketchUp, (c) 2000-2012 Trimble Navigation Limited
